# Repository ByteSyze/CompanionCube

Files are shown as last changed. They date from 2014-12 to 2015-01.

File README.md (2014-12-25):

3D-LED-Companion-Cube
=====================

This 3D LED Companion Cube project will contain all necessary information to create a 3D printed companion cube with an
internal circuit to make the hearts flash.
_____________________

The original companion cube model was created by Poh and downloaded from thingiverse here: http://www.thingiverse.com/thing:33138
_____________________
The circuit is based on an attiny13 MCU, that will require additional hardware to program 
(e.g. AVR mkII or ATMEL-ICE). All schematics and circuits are designed in KiCAD.

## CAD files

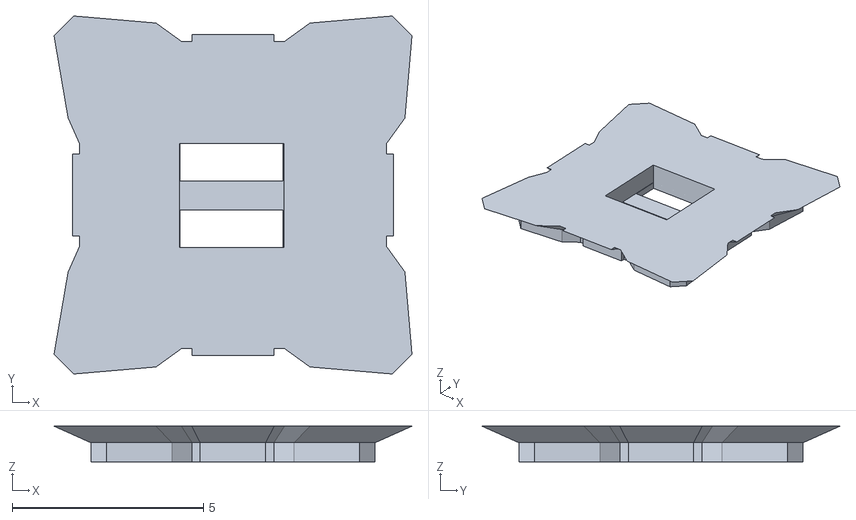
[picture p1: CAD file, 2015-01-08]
src/Model/CC_buttonholder.stl
9.36 x 9.36 x 0.932

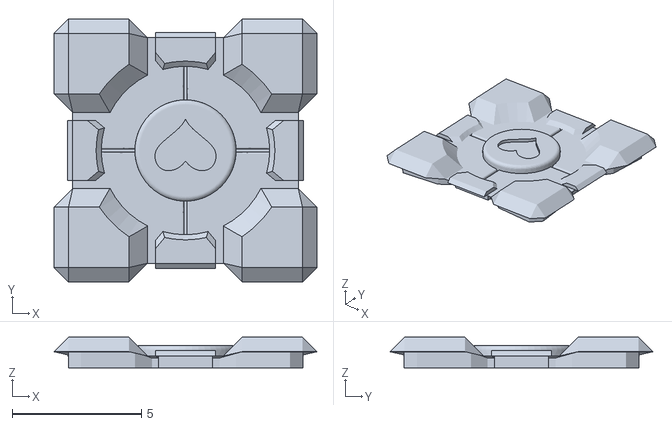
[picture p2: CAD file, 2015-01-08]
src/Model/CC_Lid.stl
10.2 x 10.2 x 1.18

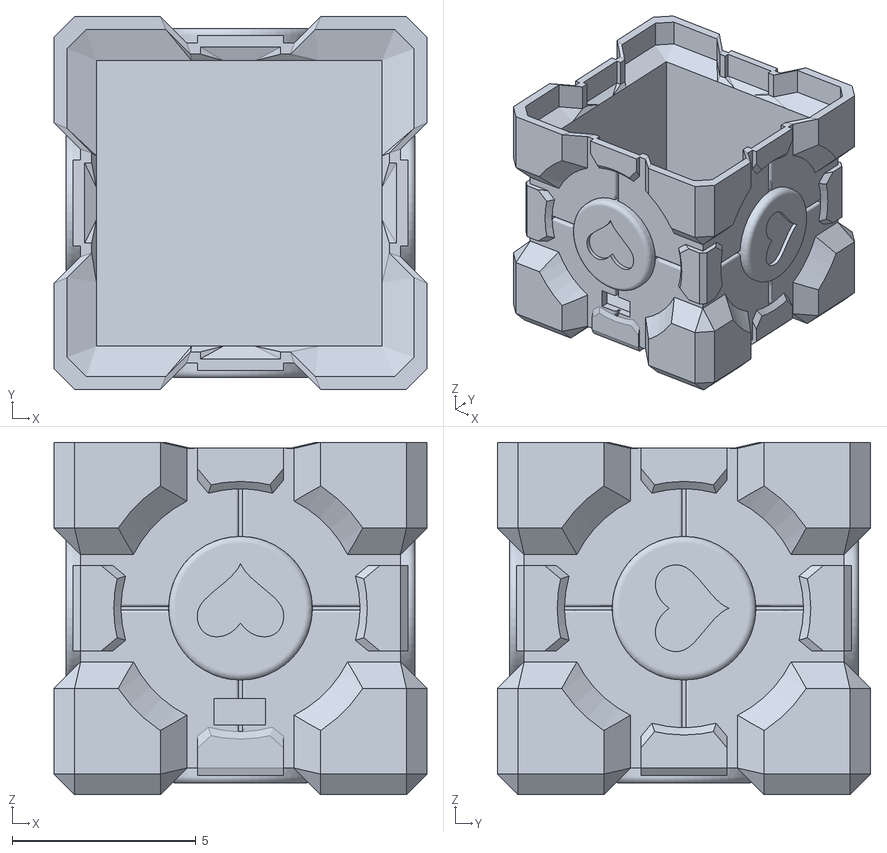
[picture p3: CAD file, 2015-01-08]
src/Model/CC_Container.stl
10.2 x 10.2 x 9.60

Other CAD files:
src/Model/Companion_Cube.blend

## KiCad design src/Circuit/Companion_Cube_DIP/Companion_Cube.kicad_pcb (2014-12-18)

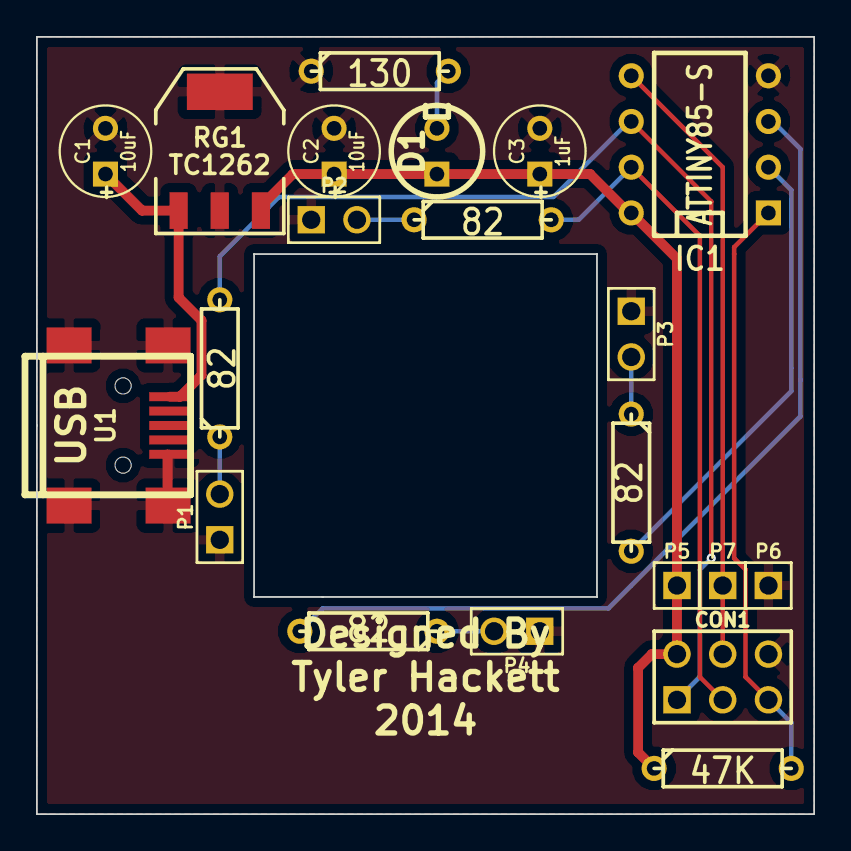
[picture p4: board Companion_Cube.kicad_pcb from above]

Board: 2 copper layers, 43.2 x 43.2 mm, 21 parts (0 on the bottom side), 14 nets.

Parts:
C1, C2: 10uF; C1V5
C3: 1uF; C1V5
CON1: AVR-ISP-6; pin_array_3x2
D1: RED; LEDV
IC1: ATTINY85-S; DIP-8__300
P1: LED_4; PIN_ARRAY_2X1
P2: LED_3; PIN_ARRAY_2X1
P3: LED_2; PIN_ARRAY_2X1
P4: LED_1; PIN_ARRAY_2X1
P5, P6, P7: CONN_1; PIN_ARRAY_1
R1, R2, R3, R4: 82; R3
R5: 130; R3
R6: 47K; R3
RG1: TC1262; SOT223
U1: MINI-B_USB; USB_MINI_B

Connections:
GND: C1.2, C2.2, C3.2, CON1.6, IC1.4, P1.1, P2.1, P3.1, P4.1, P6.1, R5.1, RG1.2, RG1.4, U1.5, U1.6, U1.7, U1.8, U1.9
unnamed: CON1.5, IC1.1, R6.2
unnamed: CON1.4, IC1.5, P7.1
unnamed: IC1.3, R4.2
unnamed: IC1.2, R3.2
unnamed: CON1.3, IC1.7, R2.2
unnamed: CON1.1, IC1.6, R1.2
unnamed: P4.2, R4.1
unnamed: D1.2, R5.2
unnamed: P3.2, R3.1
unnamed: P2.2, R2.1
unnamed: P1.2, R1.1
unnamed: C1.1, RG1.1, U1.1
VCC: C2.1, C3.1, CON1.2, D1.1, IC1.8, P5.1, R6.1, RG1.3

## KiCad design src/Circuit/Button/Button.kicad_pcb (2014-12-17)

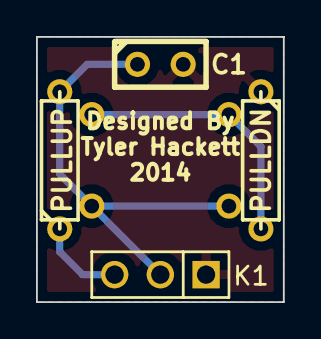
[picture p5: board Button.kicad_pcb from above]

Board: 2 copper layers, 13.7 x 14.7 mm, 5 parts (1 on the bottom side), 4 nets.

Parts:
C1: 10nF; C1
K1: CONN_3; PIN_ARRAY_3X1
R1: PULLUP; R3
R2: PULLDN; R3
SW1: SW_PUSH; SW_PUSH_SMALL

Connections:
GND: C1.2, K1.1, R2.1
unnamed: R2.2, SW1.2
unnamed: C1.1, K1.2, R1.2, SW1.1
VCC: K1.3, R1.1

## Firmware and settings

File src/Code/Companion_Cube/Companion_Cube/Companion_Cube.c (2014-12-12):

/**
 * Companion_Cube.c
 *
 * Created: 12/11/2014 5:42:15 AM
 * Author: Tyler Hackett
 *
 * This project is designed for the purpose of the "Blinky Companion Cube" project, which can be found here: 
 * https://github.com/Insomniac10102/3D-LED-Companion-Cube
 *
 */ 

#define PIN_OUT			0x01
#define PIN_IN			0x00

#define LED_LEFT		PB2 /////////////////////////////////////
#define LED_FRONT		PB1 // All of the different LED pins,  //
#define LED_RIGHT		PB4 // corresponding to the PCB layout.//
#define LED_BACK		PB3 /////////////////////////////////////

#define STATE_STARTUP	1	//Initialization state.
#define STATE_FLASH		2	//LED flashing state.
#define STATE_SLEEP		3	//Sleeping state.

#include <avr/io.h>
#include <avr/interrupt.h>
#include <avr/cpufunc.h>

unsigned char counter	= 0;	//Extra counter to increment.
unsigned char number	= 3;	//Number to display.

unsigned char button_val = 1;
unsigned char last_button_val = 1;
unsigned char button_hold_time = 0;

unsigned char state		= STATE_SLEEP; //Current state.

char get_pin(char pin)
{
	_NOP(); // First execute a no-operation, as recommended in the datasheet.
	return PINB >> pin & 0x01;
}

void set_pin(char pin, char val)
{
	if(val & 0x01)
		PORTB |= (val & 0x01) << pin;
	else
		PORTB = ~PORTB & (val & 0x01) << pin;
}

void toggle_pin(char pin)
{
	PORTB ^= 1 << PB1;
}

/**
* Sets the I/O direction of the specified pin. 1 for output, 0 for input.
*/
void set_pin_dir(char pin, char dir)
{
	DDRB |= (dir & 0x01) << pin;
}

void display_number(unsigned char num)
{
	if(num == 1)
		PORTB = 1 << LED_FRONT;
	else if(num == 2)
		PORTB = (0x1 << LED_RIGHT) | (0x1 << LED_LEFT);
	else if(num == 3)
		PORTB = (0x1 << LED_RIGHT) | (0x1 << LED_LEFT) | (0x1 << LED_BACK);
	else
		PORTB = 0x1E; //All 4 LEDs.
}

int main(void)
{
	set_pin_dir(0, PIN_IN);						// PB0 is connected to button.
	set_pin_dir(1, PIN_OUT);					// PB1-4 are LEDs.
	set_pin_dir(2, PIN_OUT);
	set_pin_dir(3, PIN_OUT);
	set_pin_dir(4, PIN_OUT);
	
	TCCR0B	|= (0x01 << CS02); //| (0x01 << CS00);	// Set prescaler to 1024; start clock.
	TIMSK0	|= (0x01 << TOIE0);					//Set timer interrupt register to go off when timer overflows.
	sei();										//Enable interrupts
	
	while(1);
}

/**Timer overflow interrupt. Called whenever the timer hits its maximum and resets.*/
ISR(TIM0_OVF_vect)
{
	last_button_val = button_val;
	button_val = (PINB >> PB0) & 0x01;
	
	if(button_val == 0)
	{
		if(last_button_val == button_val)
			button_hold_time++;
		else
			button_hold_time=0;
	}
	if(button_hold_time == 5)
	{
		if(state == STATE_SLEEP)
		{
			TCCR0B	&= ~(1 << CS00); 
			state = STATE_STARTUP;
		}
		else if(state == STATE_FLASH)
			state = STATE_SLEEP;
	}
	
	if(state == STATE_STARTUP)
	{
		if(counter % 2)
		{
			if(number % 4 == 0)
				PORTB = 0x01 << LED_RIGHT;
			else if(number % 3 == 0)
				PORTB = 0x01 << LED_BACK;
			else if(number % 2 == 0)
				PORTB = 0x01 << LED_LEFT;
			else if(number % 1 == 0)
				PORTB = 0x01 << LED_FRONT;
			
			if(++number > 16)
			{
				TCCR0B	|= (0x01 << CS02) | (0x01 << CS00);
				state = STATE_FLASH;
				number = 3;
				counter = 0;
				return;
			}
		}
		counter++;
	}	
	else if(state == STATE_FLASH)
	{
		if(counter % 2 == 0)
		{
			PORTB = 0x00; //Turn off LEDs.
		}
		else
		{
			if(number == 3 && counter < 8)
			{
				counter++;
				return; //Add some delay after 2.
			}
		
			display_number(number);
		
			if(++number > 4)
			{
				counter = 0;
				number	= 1;
				return;
			}
		}
		counter++;
	}
	else //Assume sleep
	{
		PORTB = 0x00;
	}
}

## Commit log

2014-12-04 Added initial files
    [CC_Container.stl, CC_Lid.stl, Companion_Cube.blend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]
2014-12-04 Added regulator, AVR ISP header
2014-12-05 Better origins on models
    [CC_Container.stl, CC_Lid.stl, Companion_Cube.blend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]
2014-12-05 Fixed backwards facing normal on cube lid
    [CC_Container.stl, CC_Lid.stl, Companion_Cube.blend]
2014-12-05 Fixes to overlap in top of model
    With any luck, the top lid will now fit seamlessly.
    [CC_Container.stl, CC_Lid.stl, Companion_Cube.blend]
2014-12-05 Thicker walls on container
    [CC_Container.stl, CC_Lid.stl, Companion_Cube.blend]
2014-12-05 Fixes to wall thickness
    Last changes accidentally resized a little too much. This should fix
    changes to the walls of the container and lid.
    [CC_Container.stl, CC_Lid.stl, Companion_Cube.blend]
2014-12-05 Removed use of reset pin from LED controller
    The walls of the lid have also been shortened for slightly quicker
    printing.
    [CC_Lid.stl, Companion_Cube.blend, Companion_Cube.sch]
2014-12-05 Added button schematic
    The button will be on a separate PCB so that it can be placed at the
    other side of the cube.
    The button includes a capacitor for debounce and an extra resistor as a
    precaution, incase the button is ever connected to an output*.
    *Should be safe for up to 5v, passing 20ma which is pretty common for
    MCU I/O. Requires atleast a 1/10W dissipation.
    [Button.sch, CC_Lid.stl, Companion_Cube.blend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]
2014-12-05 Fixed inclusion of container in lid STL
    This is way too easy to do.
    [CC_Container.stl, CC_Lid.stl, Companion_Cube.blend]
2014-12-05 Changes to cube model.
    [CC_Container.stl, CC_Lid.stl, Companion_Cube.blend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]
2014-12-05 Added version of cube with micro usb cutout
    [CC_Container.stl, CC_Container_MicroUSB.stl, CC_Lid.stl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]
2014-12-06 Moved debounce capacitor to behind the switch
    [Button.sch, CC_Container_MicroUSB.stl]
2014-12-06 Created button circuit
    [Button.kicad_pcb, Button.sch, Companion_Cube.sch]
2014-12-06 Initial LED driver circuit
    [Button.kicad_pcb, Companion_Cube.kicad_pcb, Companion_Cube.sch]
2014-12-06 Connected remaining ratsnets, added some logoz
    [Companion_Cube.kicad_pcb]
2014-12-07 Middle of lid is now flush with the outer rim
    The structures added by the printer make things a bigger pain than they
    should be.
    [CC_Lid.stl, Companion_Cube.blend]
2014-12-07 Added support in center of container
    The button for initiating blinky lights will sit on top of this support
    and be glued on top due to me being too lazy to think of a better way to
    attach it.
    [CC_Container_MicroUSB.stl, Companion_Cube.blend]
2014-12-07 Fixed incorrect references to the Mini USB slot
    Everything until now that has referred to USB Micro is actually USB
    Mini. Been working too much with micro's it seems.
    [CC_Container_Mini_USB.stl, Companion_Cube.blend]
2014-12-11 Redesigning circuit board for new model
    [CC_Container_Mini_USB.stl, Companion_Cube.blend, Companion_Cube.kicad_pcb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]
2014-12-11 Connected ratsnet, added some personalization
    [Companion_Cube.kicad_pcb]
2014-12-11 Attached mini USB shield pads to GND
    [Companion_Cube.kicad_pcb]
2014-12-11 Added attiny85 DIP version
    [Companion_Cube-B_Cu.gbl, Companion_Cube-B_Mask.gbs, Companion_Cube-B_SilkS.gbo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]
2014-12-11 Generated gerber files for button PCB
    [Button-B_Cu.gbl, Button-B_Mask.gbs, Button-B_SilkS.gbo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]
2014-12-11 Added timer initialization
2014-12-11 Added LED macros and display_number() function
2014-12-11 Fixed always on PB1 in display_number()
    [Companion_Cube.c]
2014-12-11 Fixed LED timing.
    The LEDs will flash a sequence of 3,4,1,2, then pause briefly and
    repeat.
    [Companion_Cube.c]
2014-12-12 Fixed timing issue in start up
    [Companion_Cube.c]
2014-12-17 Widened hole on cube circuit, smaller button PCB
    [Button-B_Cu.gbl, Button-B_Mask.gbs, Button-B_SilkS.gbo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]
2014-12-17 Adjusted the pin header on button PCB
    [Button-B_Cu.gbl, Button-B_Mask.gbs, Button-B_SilkS.gbo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]
2014-12-18 Cleaned up wiring to attiny on PCB
    [Companion_Cube.kicad_pcb]
2014-12-27 Removed center pillar on container model
    The button will no longer rest on the pillar. Instead, the lid will be 2
    separate models with the button in the middle.
    [CC_Container.stl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]
2015-01-08 Modifications to model
    Flattened the bottom of the box lid, removed center pillar in container,
    improved placement and thickness of USB mini port, added a button holder
    mesh.
    [CC_Container.stl, CC_Lid.stl, CC_buttonholder.stl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]
2015-01-16 Remove outdated circuit
    The SMD version of the board is not worth the extra effort, and the DIP
    versions are now known to work correctly.
    [Companion_Cube-B_Cu.gbl, Companion_Cube-B_Mask.gbs, Companion_Cube-B_SilkS.gbo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]
